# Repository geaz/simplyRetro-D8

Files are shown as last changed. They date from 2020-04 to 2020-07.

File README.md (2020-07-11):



This repository contains everything to rebuild the *simplyRetro D8*.
The *D8* is my first attempt to build a small custom bartop from scratch.

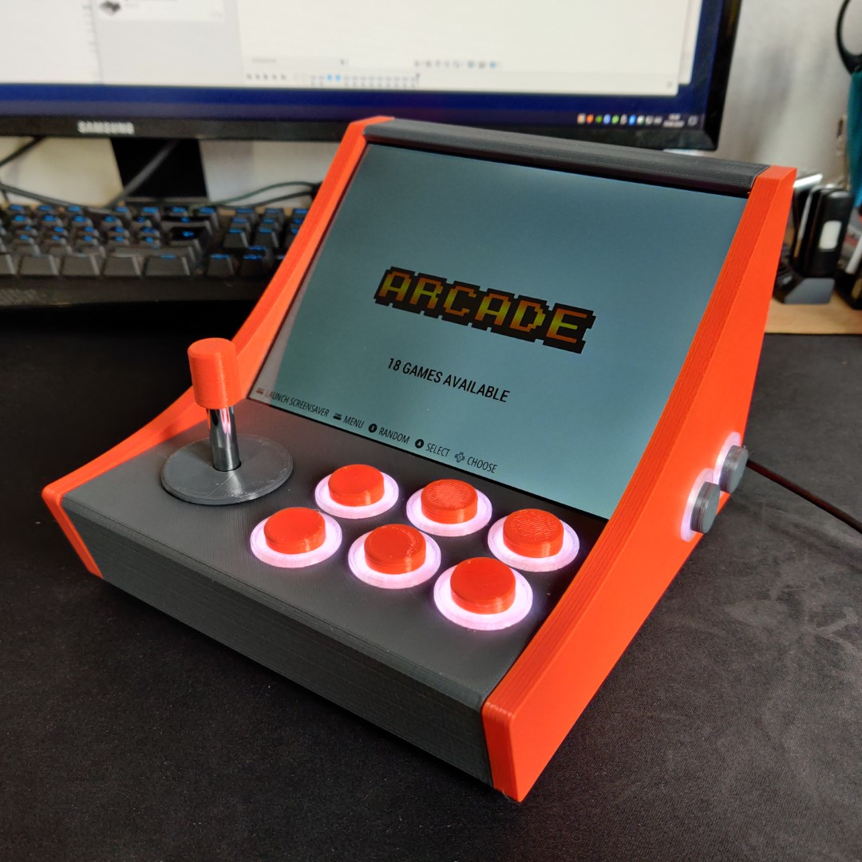
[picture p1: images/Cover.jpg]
simplyRetro D8


## Warning
This is a quite an easy build to print and assemble, but some of the screws are very hard to reach.
**I don't think you are able to pull off this build without the usage of a ratchet (a small one or one with an extension)!**

I wanted a build without any visible screws and minimal amount of parts which are able to break. There is surely a way to accomplish these tasks with better screw holes. If you know one, you are free to edit the model (Fusion 360 Archive File in the CAD folder).

Furthermore the used audio circuit is not great. Many interferences on high volumes. Go ahead and improve it, if you want.

## Features
- Custom 3D printed shell
- Stereo Speakers and Volume Control
- 12 Buttons
- 8 inch display
- Raspberry Pi 2 or 3 powered

## 3D Model
The model was designed in Fusion 360. The STLs are in the Thingiverse downloads and the Github repository. Furthermore, there is an exported Fusion 360 Archive File ready to download.

## BOM

- 3D Printed Shell (STL folder for models)
- [8 inch HDMI IPS Display](https://de.aliexpress.com/item/32325920866.html) (If you want to use another display, make sure to adapt the shell) 
- [1x PAM8403](https://de.aliexpress.com/item/32452488898.html?spm=a2g0s.9042311.0.0.1df04c4dcQesbB)
- 1x Arcade Controller Set (The controller set I bought is not available anymore! They replaced it by a set with new connectors. It seems like [these](https://www.amazon.de/dp/B074PPS84P/ref=cm_sw_em_r_mt_dp_U_qmDcFb8PJB7N4) would work fine now, but not guaranteed since I did not test them! If you want to use original arcade buttons, get buttons with a 24mm mounting diameter! Otherwise they won't fit into the mounting holes!)
- 1x Raspberry Pi 2 or 3
- 1x Power Adapter
- [2x Speaker](https://www.reichelt.de/kleinlautsprecher-k-34-wp-1w-8ohm-vis-2981-p204642.html?&trstct=pos_0) (or similar, just make sure they have a diameter of 3.4 cm or adapt the shell)
- 1x Audio Jack (male)
- 1x HDMI Cable (get a short one - the shell will already be quite crowded)
- 1x USB Type A (male) to USB Type B (male) (for arcade controller connection - see HDMI Cable note above) 
- 4x Rubber feet with M3 mounting holes
- 12x M3x8mm screws (torx screws are highly recommended)
- Zip Ties
- Velcro or double-faced adhesive tape to attach the PAM, Arcade Controller Board and Display Board
- Electrical Tape
- Wire :)

## Build

### Shell

**For this part you have to use a ratchet. I don't think that all screws are accessible without one!** 
To make your life a bit easier, preinsert eight screws into the holes on the *Back Panel* and *Front Panel*. Furthermore, I recommend to widen the first millimeter of the holes on the side panels a bit. 

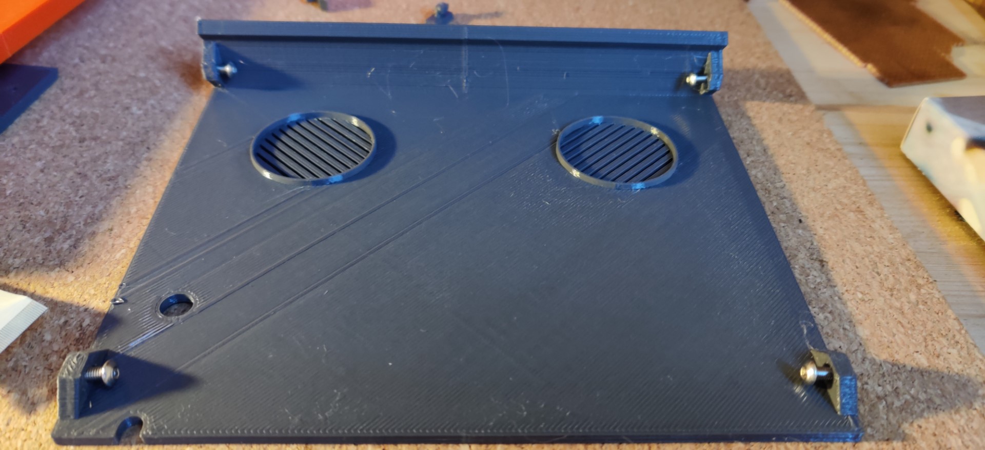
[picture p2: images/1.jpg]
Screw in Shell


Screw the *Front Panel* and *Back Panel* to one of the side panels. Then insert the display into the slot and screw the remaining side panel. **The last top screw of the *Back Panel* will be painful! Use your ratchet!**

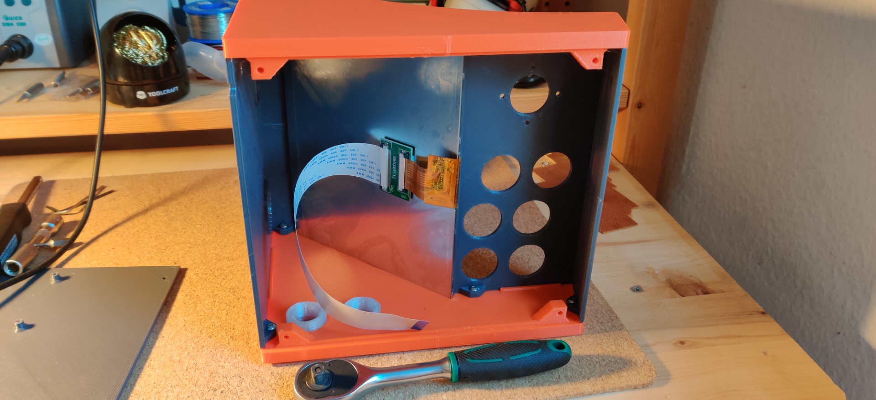
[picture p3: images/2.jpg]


### Control Boards

I mounted the display and arcade controller boards to the back of the display. **Make sure that you use electrical tape to mask the back of the boards (or the whole display back), before you attach them with the velcro or double-faced tape. Otherwise, it is possible that you short them!**

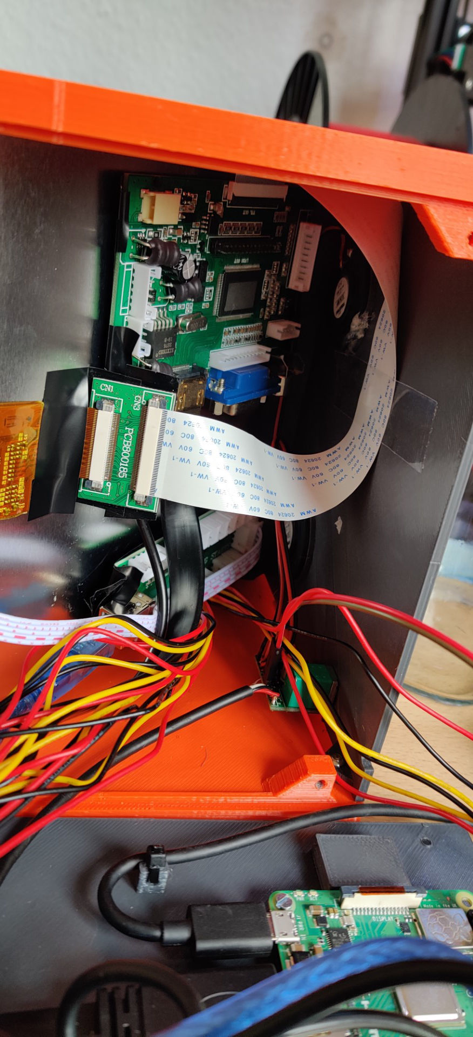
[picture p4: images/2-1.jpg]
Control Boards


### Arcade Stick

To fit the arcade stick into the shell you have to remove the mounting plate and do something about the two holes (see picture - I added a red circle on one of them). You have two options here:

1. Use the controller in the direction it was intended, but you will have to remove the two little holes. Otherwise, it won't fit into the shell.
2. Remove the transparent part at the bottom, remove the circuit with the switches and rotate it by 90°. This way it will fit, but you have to rebind the arcade stick controls in your OS later.

I went for option two. My controller board had a defect and I was not able to use the *select* button plug. Thats why I had to remap the arcade controls either way.

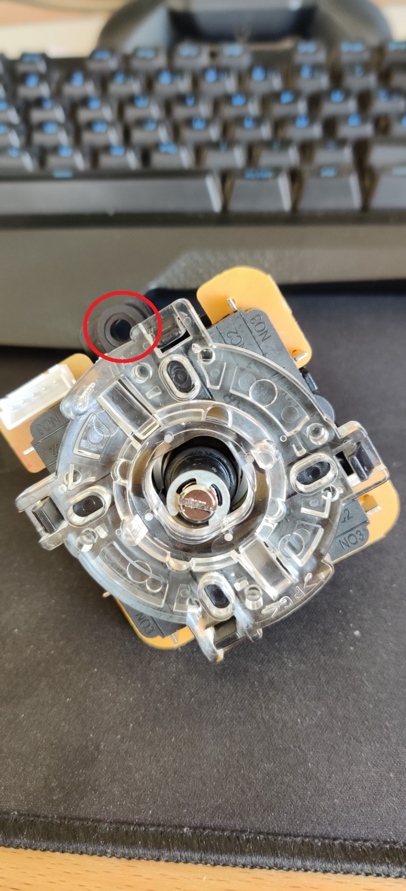
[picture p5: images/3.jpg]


You should be able to use the screws of the mounting plate to mount the stick to the shell.

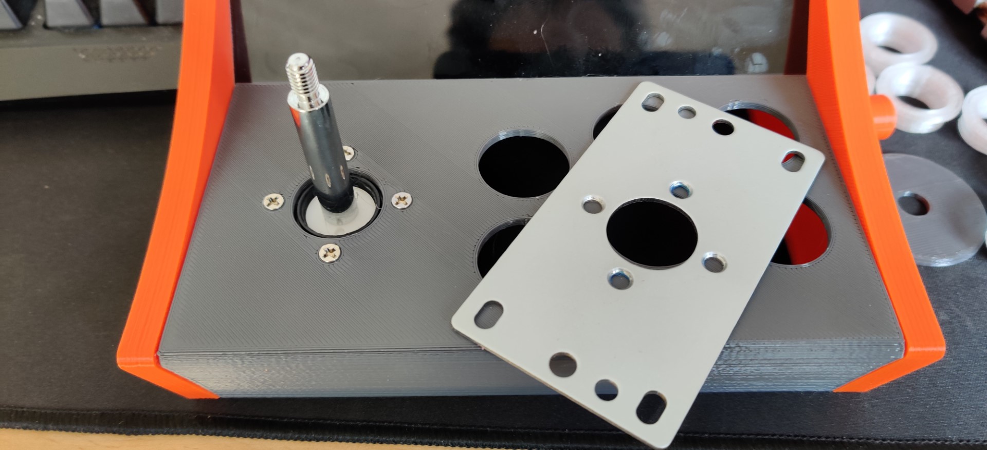
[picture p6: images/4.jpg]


Add the *Duster* and screw the *Joystick Ball* to the top of the stick.

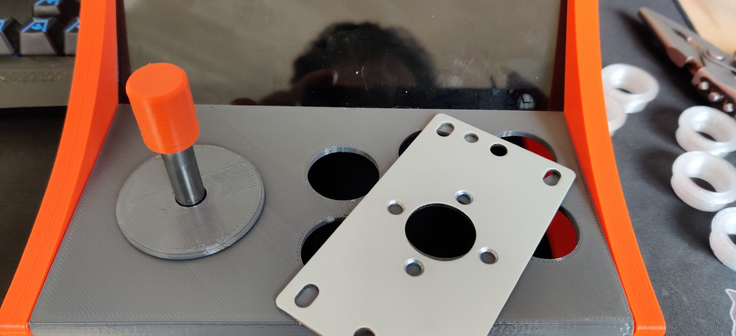
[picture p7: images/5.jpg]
Joystick Ball


### Buttons

**If you want to use original 24mm arcade buttons, you are free to skip this section.**

You have to disassemble the arcade buttons to use the custom housing. Remove the top of the buttons and use a caliper to press the led circuit out of the housing. Removing the switch should be straight forward (a flat screwdriver helps).

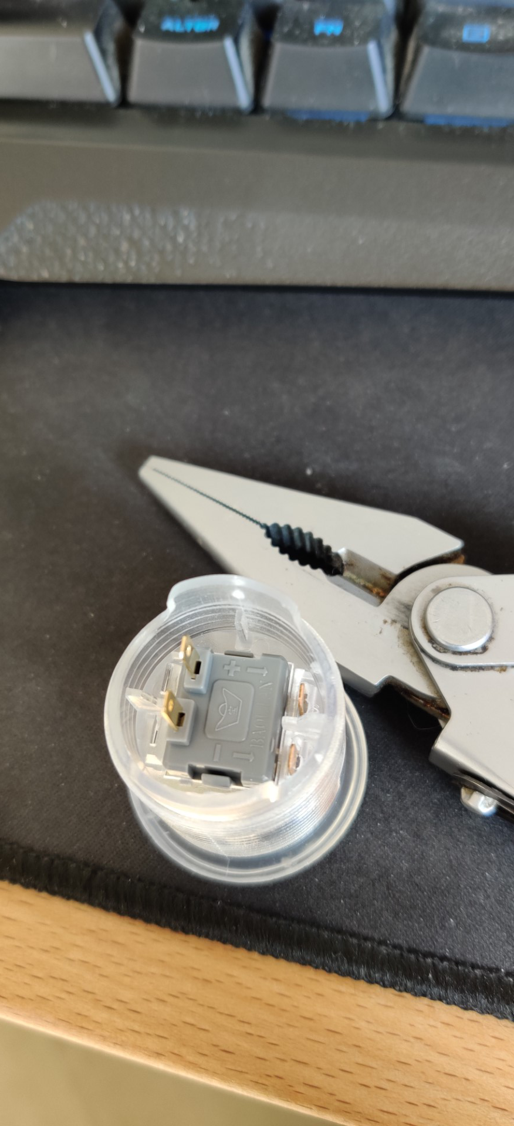
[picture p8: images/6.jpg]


First insert the switch to the custom housing (once pressed into the housing it is hard to remove). Then insert the led circuit. This will be a tight fit. Use a bit force if necessary (or *The Force*
, if it helps).

Now it would be a good point to test the LEDs. Some of mine did not work anymore after these steps. Heating the contacts of the resistor solved the problem in my case. 

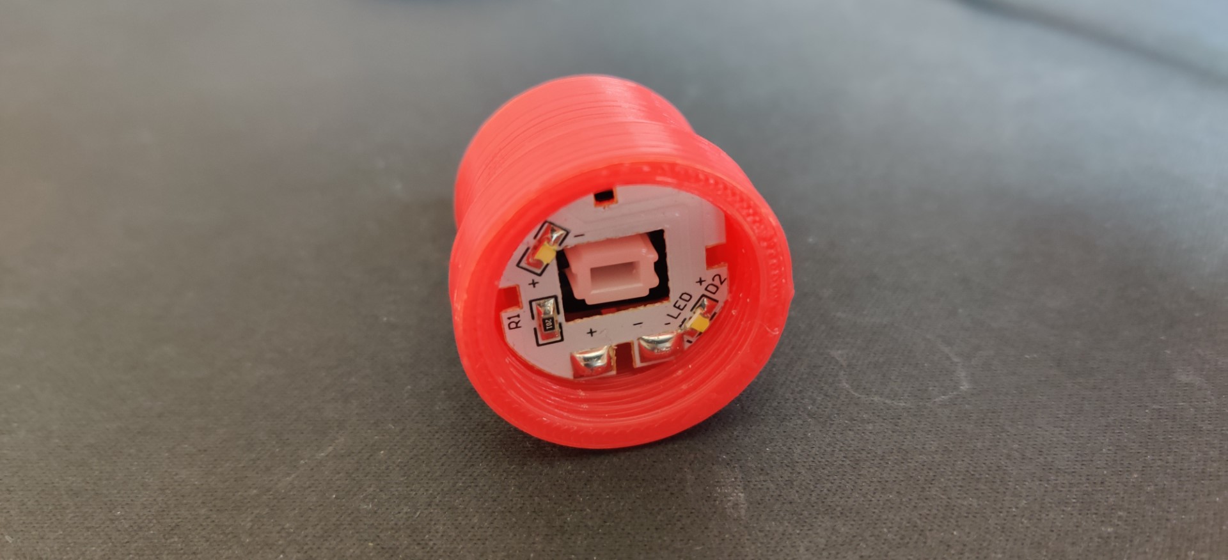
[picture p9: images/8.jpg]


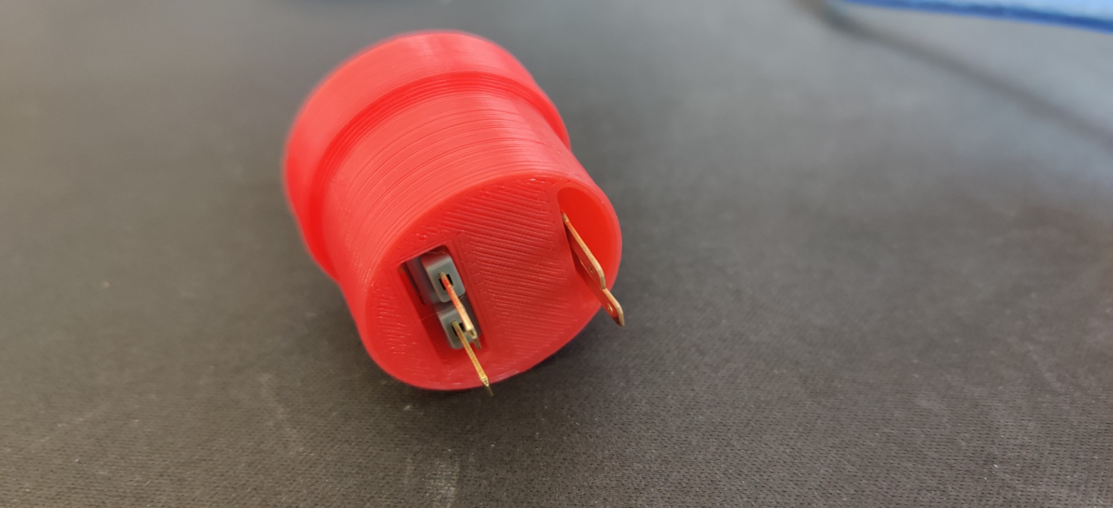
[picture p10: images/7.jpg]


Insert the *Button Top*s into the *Front Panel* and mount the *Button Housing*s. Same goes for the *Side Button Top*s.

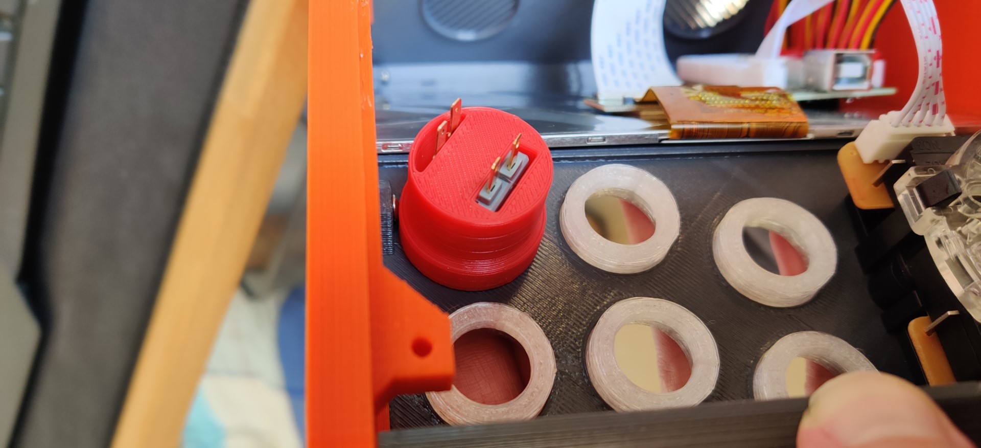
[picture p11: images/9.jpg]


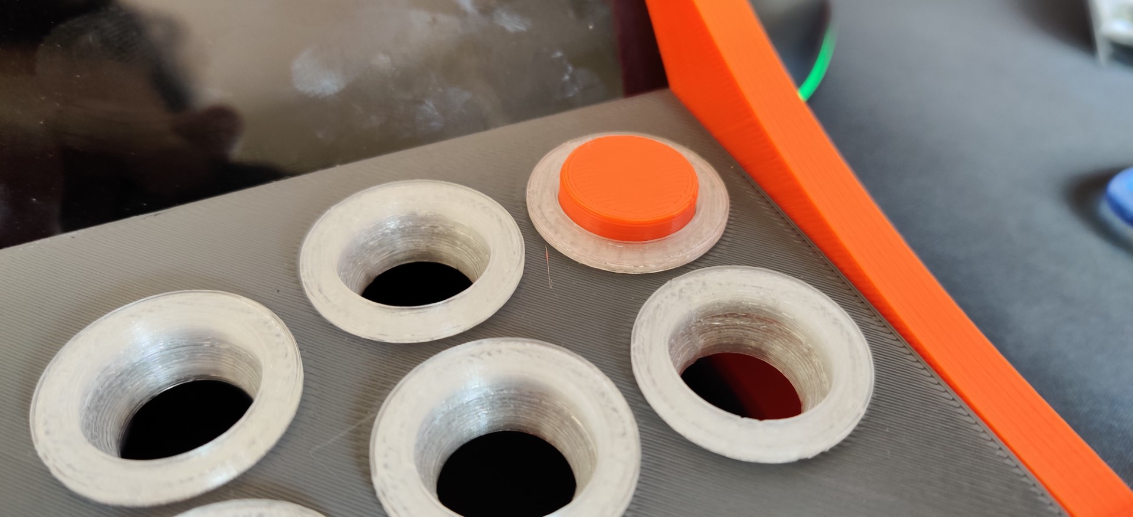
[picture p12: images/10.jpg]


After wiring the buttons bend the pins a bit. Otherwise, you won't be able to close the shell in the last step. **I had to insulate two of the pins. Because of the tight fit of the components, on some pins it was possible to introduce a short once th shell was closed. Check your pins!**

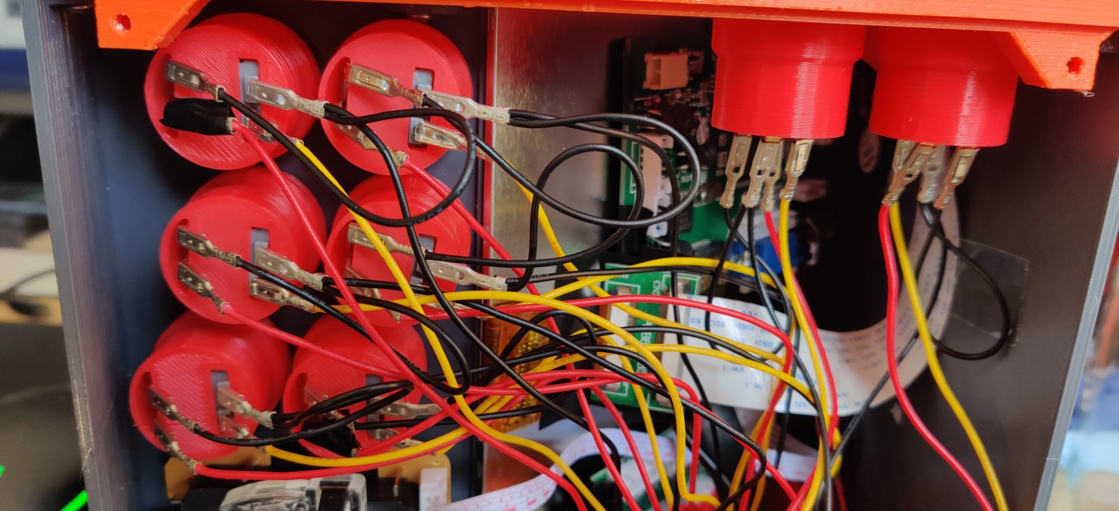
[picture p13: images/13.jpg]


### Audio

Take the pictures as a reference for the audio *circuit*. This should be straightforward. The top part of the audio jack is the *Left* channel, the middle part the *Right* channel and the bottom part is *Ground*. Insert the speakers into the *mounting circles* of the *Back Panel*. Just use a drop of hot glue, if it is not a press fit in your case. Mount the PAM to the *Back Panel*.

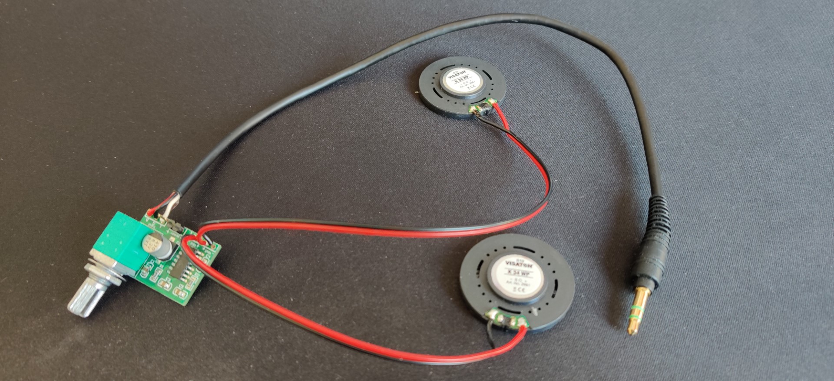
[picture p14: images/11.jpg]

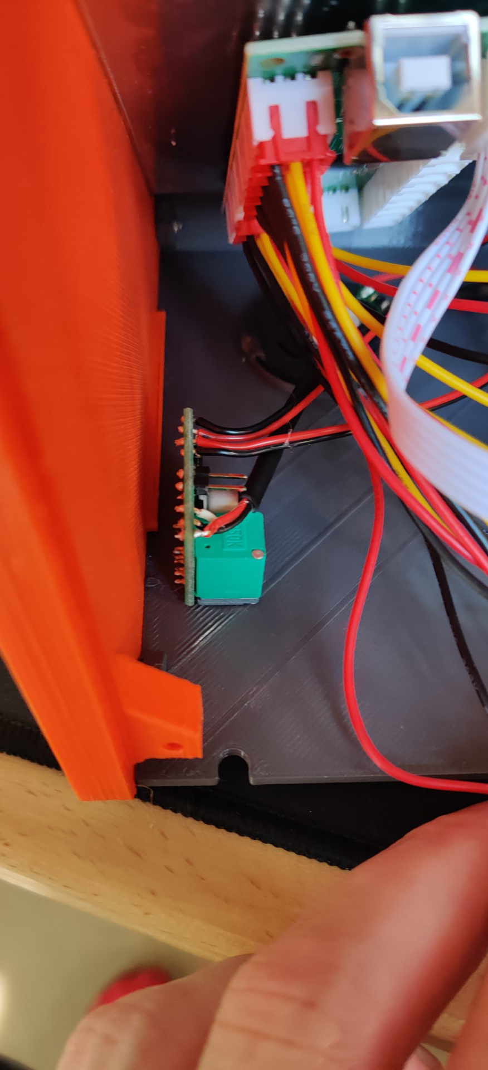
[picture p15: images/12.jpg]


### Raspberry Pi and closing the shell

Mount the Raspberry Pi to the *Bottom Panel* and insert the power adapter, HDMI and USB plugs into it (Arcade Controller and Display). Don't forget to zip tie the power adapter cable to secure it (see picture). 

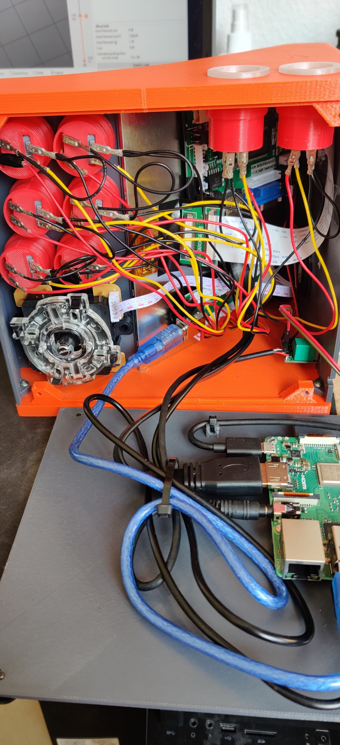
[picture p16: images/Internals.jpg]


Now configure your retro system as you want and close the shell - use the rubber feet. You are done!
I used [RetroPie](https://retropie.org.uk/) together with the [simplyRetro theme](https://github.com/geaz/simplyRetro-Z5/releases/download/v1.4/simplyRetro.Theme.zip).

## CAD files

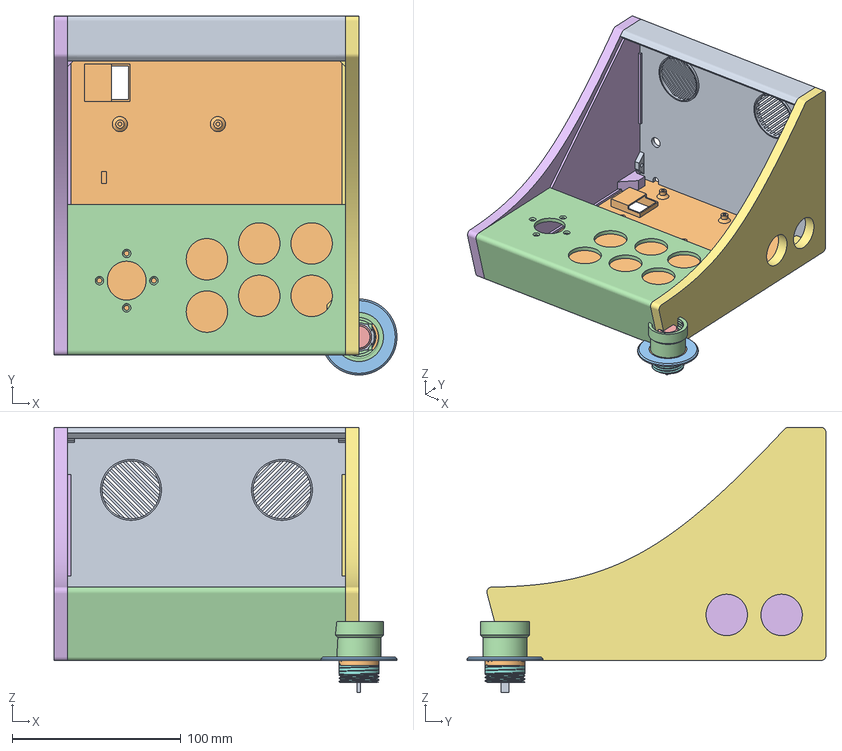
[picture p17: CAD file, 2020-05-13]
simplyRetro D8.3mf
203.0 x 212.5 x 157.0 mm
1x Back Panel.stl
1x Bottom Panel.stl
1x Duster.stl
1x Front Panel.stl
1x Joystick Ball.stl
1x Left Panel.stl
1x Right Panel.stl
2x Side Button Top.stl
2x Side Button.stl
6x Button Top.stl
6x Button.stl
8x Button Housing.stl

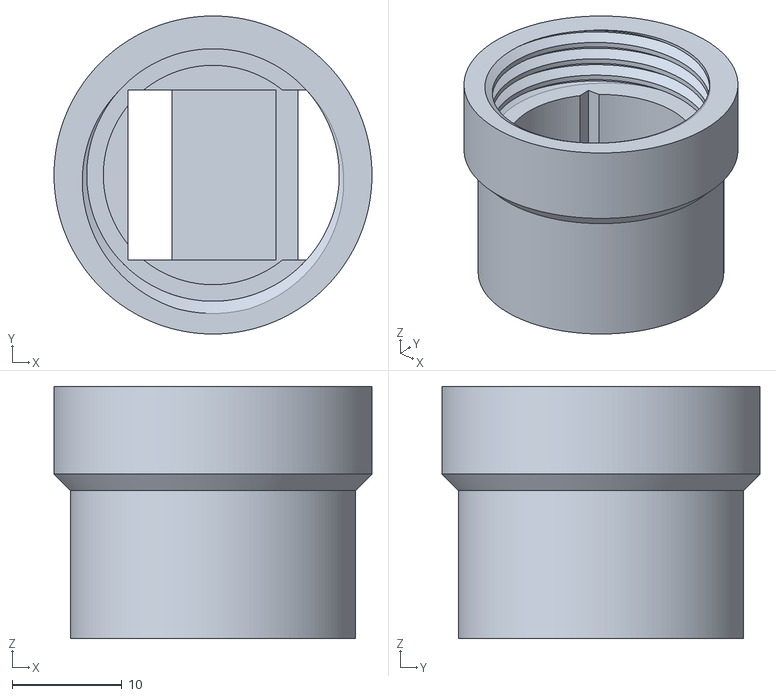
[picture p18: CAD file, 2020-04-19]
stl/8x Button Housing.stl
29.0 x 29.0 x 23.0

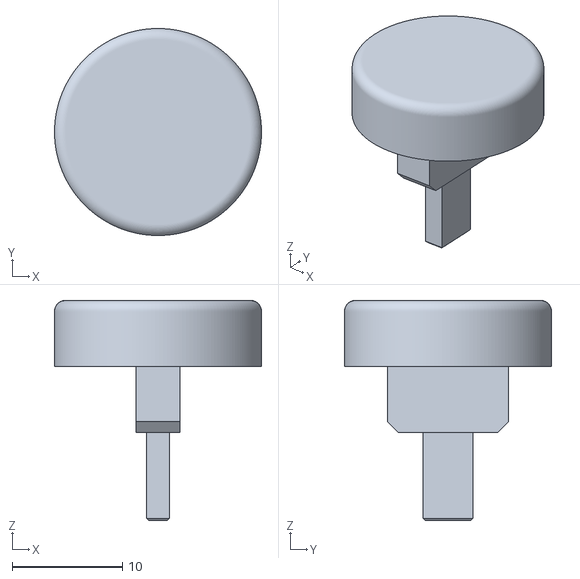
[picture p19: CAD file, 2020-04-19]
stl/6x Button.stl
18.8 x 18.8 x 20.0

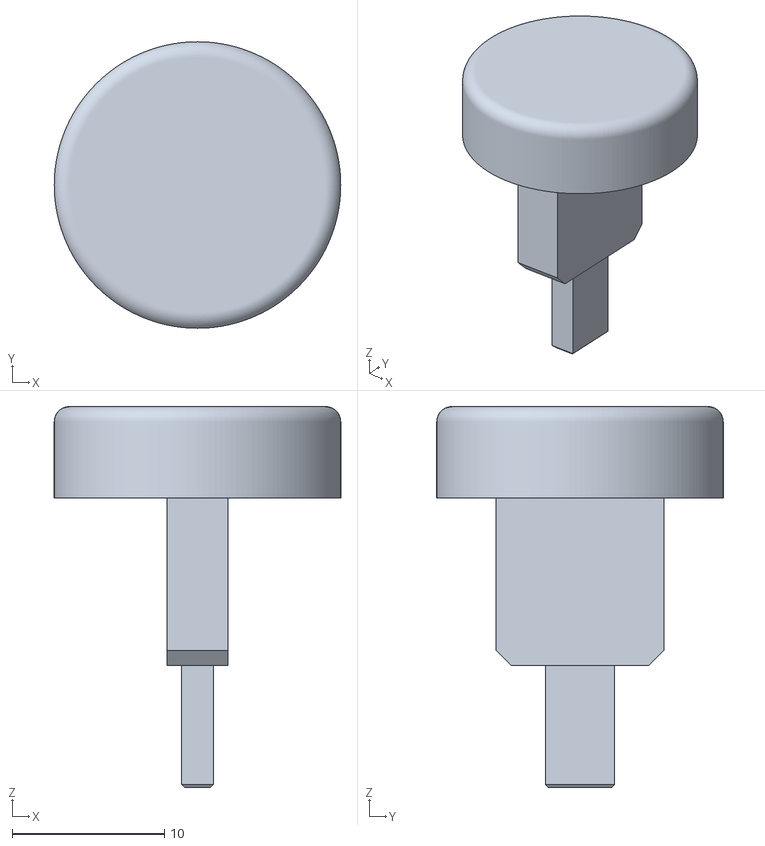
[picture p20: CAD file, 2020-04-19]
stl/2x Side Button.stl
18.8 x 18.8 x 25.0

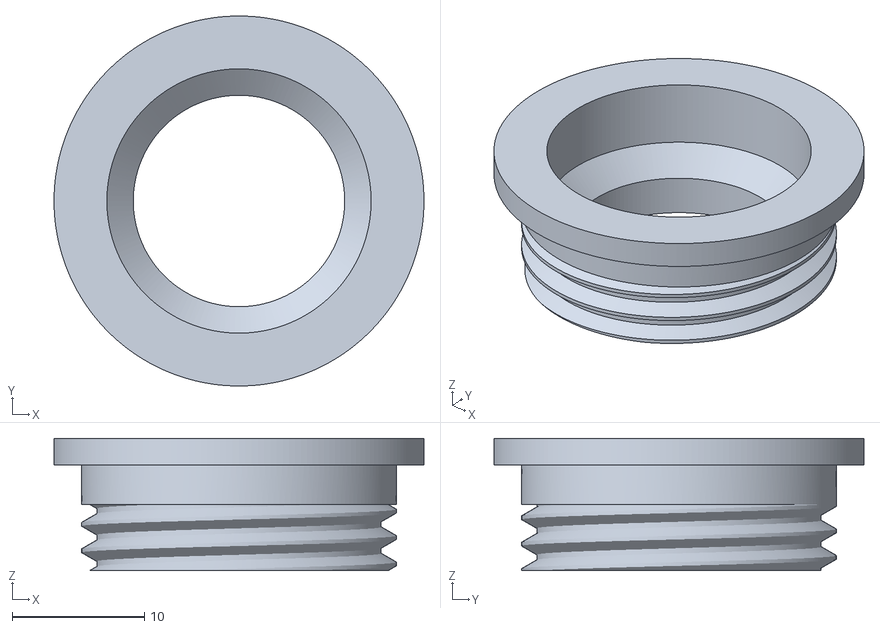
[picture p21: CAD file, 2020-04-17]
stl/6x Button Top.stl
28.0 x 28.0 x 10.0

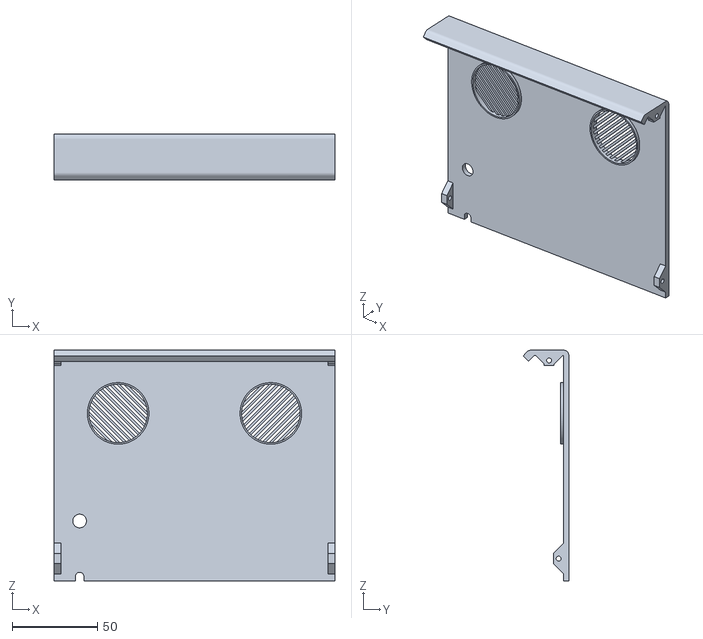
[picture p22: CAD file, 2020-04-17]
stl/1x Back Panel.stl
164.5 x 26.8 x 135.0

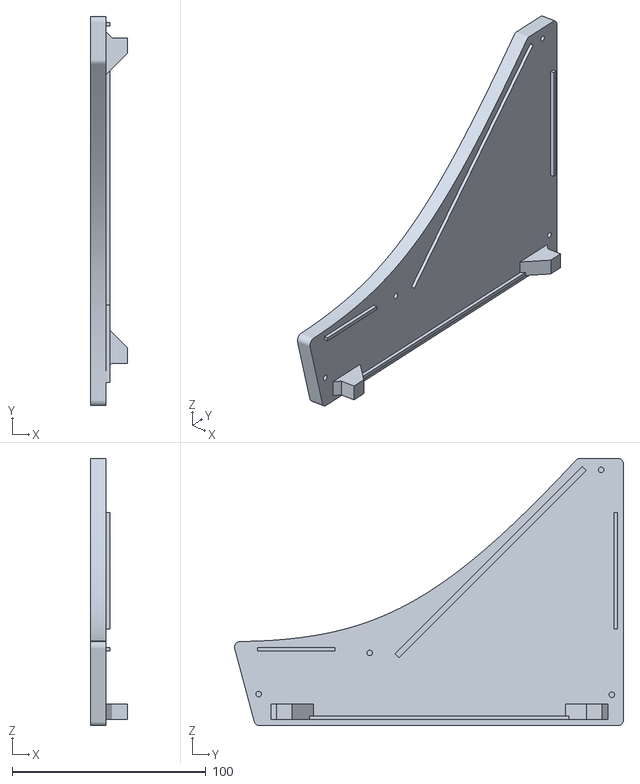
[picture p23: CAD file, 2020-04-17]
stl/1x Left Panel.stl
19.0 x 200.7 x 138.0

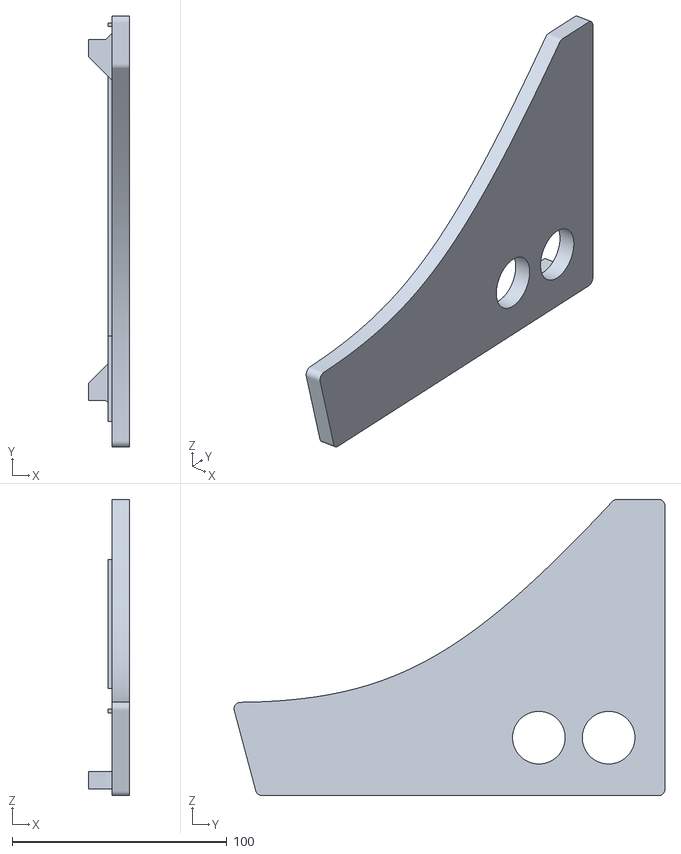
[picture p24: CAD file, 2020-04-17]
stl/1x Right Panel.stl
19.0 x 200.7 x 138.0

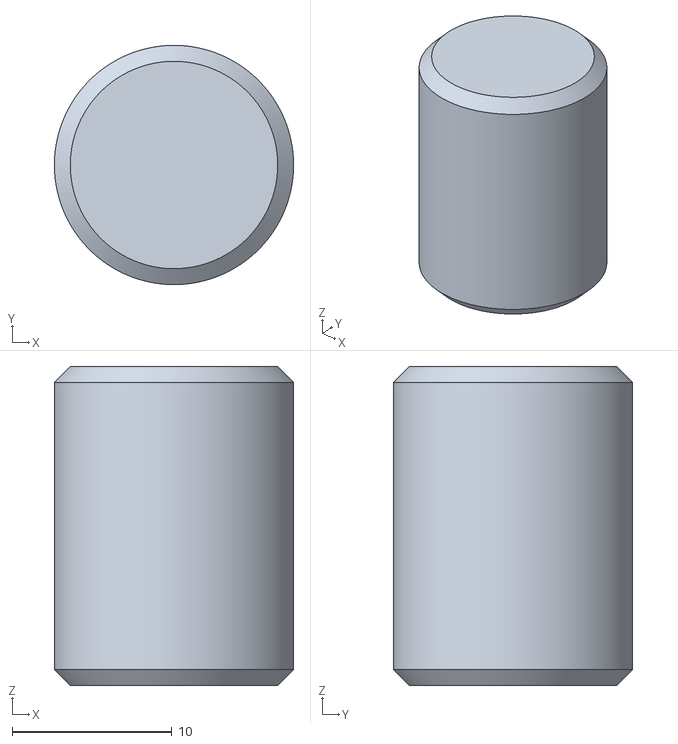
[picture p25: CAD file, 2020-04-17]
stl/1x Joystick Ball.stl
15.0 x 15.0 x 20.0

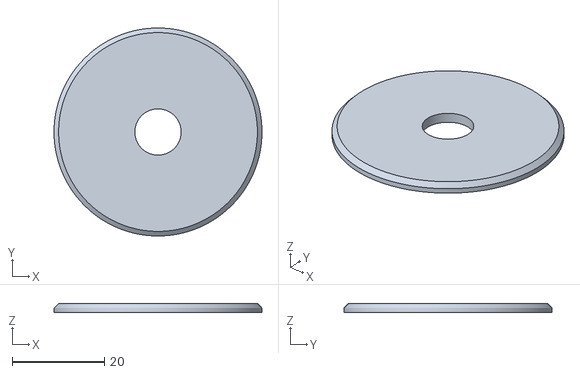
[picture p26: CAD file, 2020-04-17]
stl/1x Duster.stl
45.0 x 45.0 x 2.00

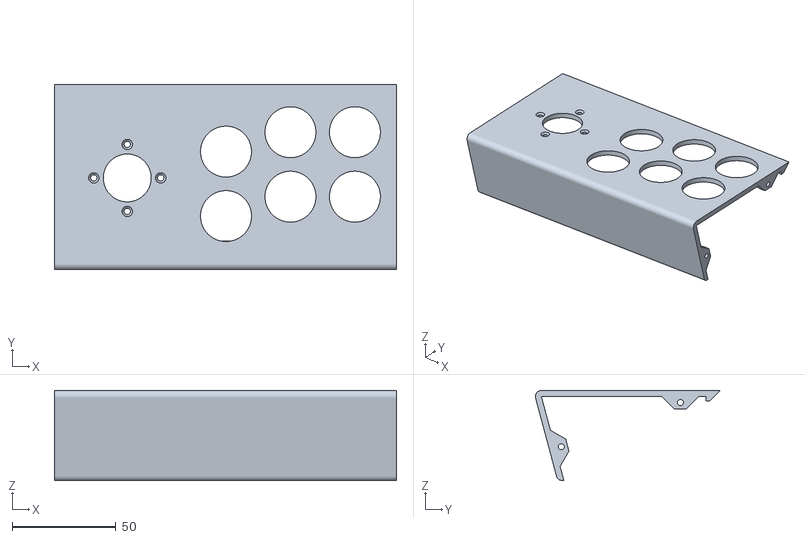
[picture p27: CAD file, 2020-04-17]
stl/1x Front Panel.stl
164.5 x 89.1 x 43.5

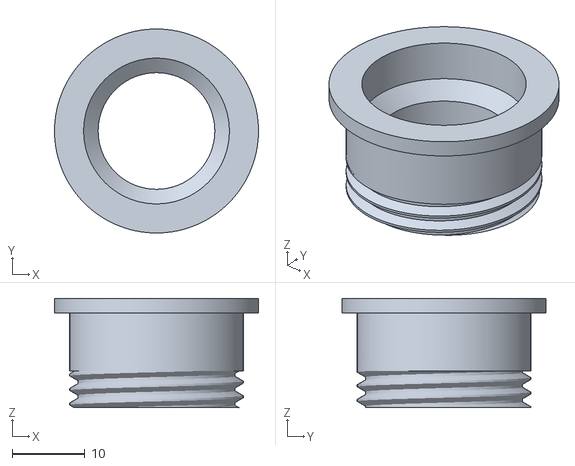
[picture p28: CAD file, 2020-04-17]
stl/2x Side Button Top.stl
28.0 x 28.0 x 15.0

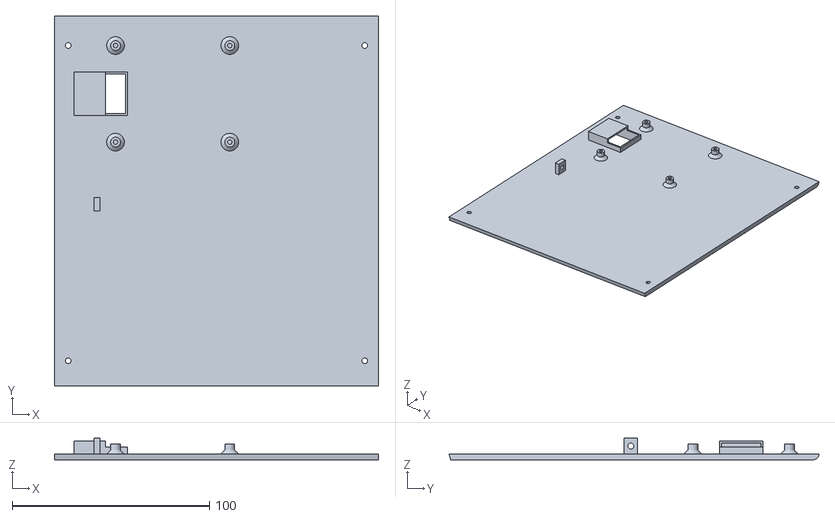
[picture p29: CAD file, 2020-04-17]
stl/1x Bottom Panel.stl
164.5 x 187.8 x 11.0

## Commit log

2020-04-17 Add STLs
    [1x Back Panel.stl, 1x Bottom Panel.stl, 1x Duster.stl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]
2020-04-18 Remove 0.2mm (diameter) from buttons
    [2x Side Button.stl, 6x Button.stl]
2020-04-18 Revert Button change
    [2x Side Button.stl, 6x Button.stl]
2020-04-19 Redesign buttons
    [2x Side Button.stl, 6x Button.stl, 8x Button Housing.stl]
2020-05-13 Add 3D2P 3MF
    [simplyRetro D8.3mf]
